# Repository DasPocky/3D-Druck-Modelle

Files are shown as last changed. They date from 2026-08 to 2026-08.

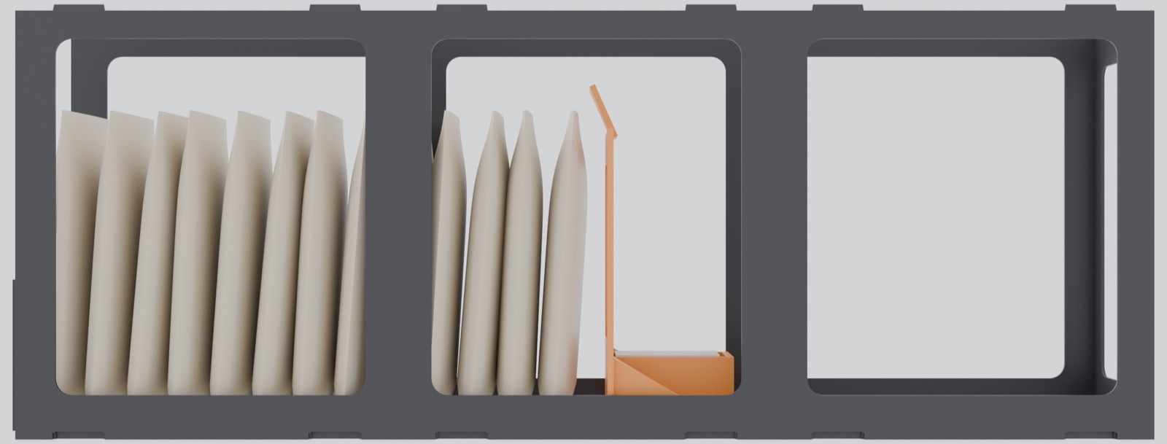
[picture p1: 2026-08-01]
FutterStorage/bilder/web/b_gefuellt.jpg

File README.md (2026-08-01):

# 3D-Druck-Modelle

Meine selbst konstruierten Modelle für den 3D-Druck. Jedes Projekt liegt in
einem eigenen Ordner und ist für sich abgeschlossen — Quelldateien, fertige
STLs, Zeichnungen und Anleitung gehören zusammen.

---

## Projekte

| Projekt | Worum es geht | Druckbett ab |
|---|---|---|
| [FutterStorage](FutterStorage/) | Regalsystem für 85-g-Nassfutterbeutel. Waagerechte Kanäle, eine Konstantkraftfeder schiebt die Beutel nach vorn. 5 × 3 Ebenen = 330 Beutel. | 180 × 180 mm |

---

## Aufbau eines Projekts

Die Ordner folgen überall demselben Schema:

| Ordner | Inhalt |
|---|---|
| `modell/` | Die Quelle — meist OpenSCAD, alle Maße als Variablen |
| `werkzeuge/` | Skripte, die alles Weitere daraus erzeugen |
| `stl/` | Druckfertige Bauteile |
| `zeichnungen/` | Bemaßte SVG-Blätter |
| `bilder/` | Renderings |
| `paket/` | Die fertige Dokumentation zum Weitergeben |

Geändert wird nur in `modell/` und `werkzeuge/`. Alles andere entsteht daraus
neu — die jeweilige Projekt-README sagt, mit welchem Befehl.

Fertige `.zip`-Pakete liegen bewusst nicht im Repo. Sie werden beim Bauen
erzeugt und wären hier nur eine Kopie von allem anderen.

---

## Drucken

Wer nur drucken will, braucht nichts zu installieren: Die STLs liegen fertig
im Repo. Ordner öffnen, `stl/*.stl` herunterladen, in den Slicer ziehen. Die
Projekt-README nennt Material, Schichthöhe und was sonst noch gebraucht wird.

---

## Lizenz

Privates Projekt, keine Garantie auf irgendwas. Nachdrucken und anpassen
ausdrücklich erwünscht.

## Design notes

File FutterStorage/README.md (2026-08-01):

# FutterStorage

Ein gedrucktes Regalsystem für 85-g-Nassfutterbeutel (Purina Gourmet, Felix
und Baugleiches). Waagerechte Kanäle über die volle Schranktiefe, eine
Konstantkraftfeder schiebt die Beutel nach vorne, entnommen wird immer der
vorderste. Die Ebenen stehen direkt aufeinander — kein toter Raum.

Gegriffen wird an der **Oberkante** des Beutels: über ihm bleiben 42 mm
Greifraum, gerade so viel, dass zwei Finger neben die Kante passen. Diese
42 mm bestimmen die Ebenenhöhe von 182,8 mm und damit, dass drei Ebenen
550 mm Fachhöhe brauchen.

**Ausbau:** 5 Spalten × 3 Ebenen = 15 Sorten, 330 Beutel
**Passt in:** 540 × 500 × 550 mm nutzbaren Schrankraum
**Druckbett:** ab 180 × 180 mm (Bambu Lab A1 mini)

---

## Schnellstart

```bash
python3 werkzeuge/stl-bauen.py     # Bauteile erzeugen
python3 werkzeuge/pruefen.py       # prüfen, bevor gedruckt wird
```

Dann `stl/*.stl` in den Slicer. Die vollständige Anleitung liegt in
`paket/index.html` — dort steht auch, was gekauft werden muss.

---

## Aufbau

| Ordner | Inhalt | Herkunft |
|---|---|---|
| `modell/` | Die OpenSCAD-Quelle — alle Maße als Variablen | von Hand |
| `werkzeuge/` | Skripte, die alles Weitere erzeugen | von Hand |
| `stl/` | Druckfertige Bauteile; `segmente/` enthält die 27 Varianten | erzeugt |
| `zeichnungen/` | Sieben bemaßte SVG-Blätter | erzeugt |
| `bilder/` | Renderings in voller Auflösung | erzeugt |
| `paket/` | Die fertige Dokumentation zum Weitergeben | erzeugt |

Geändert wird ausschließlich in `modell/` und `werkzeuge/`. Alles andere
entsteht daraus neu.

### Die Skripte

| Datei | Was sie tut |
|---|---|
| `stl-bauen.py` | Ruft OpenSCAD je Bauteil auf, prüft Stapel und Spalten auf Kollision |
| `pruefen.py` | Wasserdicht, Volumen, Überhänge, Bauraum, Passung — bricht bei Fehlern ab |
| `zeichnungen.py` | Bemaßte SVG-Blätter, prüft sich selbst auf Überdeckungen |
| `rendern.py` | Blender-Szenen mit automatischer Kamerarahmung |
| `schilder.py` | Ein Schild je Futtersorte, als STL und als Bild |
| `symbole-holen.py` | Wandelt die OpenMoji-SVG in OpenSCAD-Polygone |
| `symbole-pruefen.py` | Misst jedes Sortensymbol auf Zentrierung und Größe |
| `webbilder.py` | Verkleinert die Renderings zu JPEG für die Seiten |
| `abgleich.py` | Hält Modell, STL, Zeichnungen und Bilder gegeneinander |
| `seiten.py` | Baut die HTML-Dokumentation und das ZIP |

### Alles neu bauen

```bash
python3 werkzeuge/stl-bauen.py
python3 werkzeuge/pruefen.py
python3 werkzeuge/symbole-pruefen.py
python3 werkzeuge/schilder.py beide
python3 werkzeuge/zeichnungen.py
for s in front mitte end schieber schild kanal explosion gefuellt ebene gesamt \
         entnahme greifraum varianten varianten_spalte; do
    blender -b -P werkzeuge/rendern.py -- $s bilder/b_$s.png
done
python3 werkzeuge/webbilder.py    # verkleinerte JPEG für die Seiten
python3 werkzeuge/seiten.py
python3 werkzeuge/abgleich.py     # prüft alles gegeneinander
```

---

## Anpassen

Alle Maße stehen oben in `modell/katzenfutter-regal.scad`. Die wichtigsten:

| Variable | Standard | Wirkung |
|---|---|---|
| `beutel_breit` | 88 | bestimmt die Spaltenbreite und damit, wie viele Spalten passen |
| `beutel_hoch` | 136 | bestimmt zusammen mit `luft_oben` die Ebenenhöhe |
| `luft_oben` | 42 | Greifraum über dem Beutel — darunter wird die Entnahme zur Fummelei |
| `beutel_dicke` | 19 | bestimmt die Kapazität je Kanal |
| `segment_laenge` | 160 | muss auf das Druckbett passen |
| `passung` | 0,2 | Spiel je Flanke — bei strammem Sitz erhöhen |
| `schild_text` | HUHN | Aufdruck des Schilds |
| `schild_symbol` | huhn | Tiersymbol daneben |

Nach jeder Änderung `stl-bauen.py` und `pruefen.py` laufen lassen. Zeichnungen
und Renderings lesen die Maße selbst aus dem Modell und passen sich an.

---

## Sortensymbole

Die acht Tiersilhouetten stammen aus [OpenMoji](https://openmoji.org)
(CC BY-SA 4.0) und liegen als SVG unter `modell/symbole/`.
`symbole-holen.py` wandelt sie in OpenSCAD-Polygone — OpenSCAD kann kein
SVG lesen. Bei Weitergabe gehört die Namensnennung dazu, Einzelheiten in
[modell/symbole/HERKUNFT.md](modell/symbole/HERKUNFT.md).

---

## Die 27 Segmentvarianten

Ein Segment sitzt an drei Stellen zugleich, und an jedem Rand des Verbunds
fällt weg, was ins Leere greifen würde:

| Achse | Werte | Was sich ändert |
|---|---|---|
| Tiefe | `front` · `mitte` · `end` | Anschlagwand vorne, Rückwand hinten |
| Höhe | `unten` · `mitte` · `oben` | oben ohne Stapelzapfen, unten ohne Taschen |
| Breite | `links` · `mitte` · `rechts` | außen ohne Verbindertasche |

Der Vollausbau braucht 45 Segmente, und jede der 27 Varianten kommt darin
mindestens einmal vor. `stl-bauen.py` gibt die Stückliste am Ende aus.

---

## Wie der Verbund zusammenhält

Zwei Steckverbindungen, beide ohne Zusatzteile und ohne Stützmaterial:

- **Nach oben** laufen die Seitenwände als Zapfen weiter und stecken in Taschen
  im Boden der Ebene darüber.
- **Zur Seite** greift eine Nase am Bodenrand in die Tasche der Nachbarspalte.
  Beide liegen unterhalb des Innenraums und kosten keinen Beutelplatz.

`stl-bauen.py` prüft nach jedem Lauf, dass sich weder gestapelte Ebenen noch
benachbarte Spalten durchdringen.

---

## Was gekauft werden muss

Je Kanal eine **Konstantkraftfeder CF025-0198** (8,8 N, Auszug 557 mm,
Band 12,7 mm) und einen **3-mm-Rundstab aus Edelstahl** als Achse. Sonst
nichts — keine Schrauben, keine Muttern, kein Kleber.

Die Feder wickelt **nicht** direkt auf der Achse: dafür liegt
`stl/trommel.stl` bei, die frei auf ihr läuft. Bezugsquellen, Preise und
die Begründung der Auswahl stehen in [BAUTEILE.md](BAUTEILE.md).

---

## Vor dem Serienstart

`stl/probe.stl` drucken (34 g, gut eine halbe Stunde) und einen echten Beutel
hineinstellen. Passt er mit zwei Millimetern Luft, stimmen alle weiteren Maße.

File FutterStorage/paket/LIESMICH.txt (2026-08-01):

FUTTERSTORAGE
=============

Oeffne index.html im Browser - von dort aus ist alles verlinkt.

  index.html          Uebersicht und Einstieg
  bauanleitung.html   Was gedruckt und gekauft wird, wie es zusammengeht
  technik.html        Wie das Modell entstanden ist, Code und Werkzeuge
  zeichnungen.html    Die fuenf bemassten Blaetter zum Durchblaettern
  galerie.html        Alle zehn Renderings, klickbar in voller Groesse

  stl/                Sieben druckfertige Dateien fuer den Slicer
  zeichnungen/        Sieben bemasste Blaetter (SVG, beliebig skalierbar)
  bilder/             Zehn Renderings in voller Aufloesung (PNG)
  web/                Dieselben Bilder klein - werden von den Seiten geladen
  modell/             Die OpenSCAD-Quelldatei, alle Masse parametrisch

Die Seiten laufen ohne Internet: einfach index.html doppelklicken.
Alle Masse in Millimetern.

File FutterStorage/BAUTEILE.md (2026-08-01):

# Was gekauft werden muss

Alles andere wird gedruckt. Für einen Kanal braucht es genau zwei Zukaufteile:
eine Konstantkraftfeder und einen Rundstab als Achse.

Stand der Recherche: 1. August 2026. Preise und Verfügbarkeit im Shop prüfen.

---

## Wie die Federkraft zustande kommt

Die Feder muss zwei Grenzen einhalten — deshalb steht die Rechnung hier
und nicht nur das Ergebnis.

**Nach unten** begrenzt die Reibung des vollen Stapels:

| | |
|---|---|
| 22 Beutel × 85 g | 1,870 kg = 18,3 N Gewichtskraft |
| Reibbeiwert Folie auf PLA | 0,3 bis 0,4 (am Teil zu messen) |
| **nötige Schubkraft** | **5,5 bis 7,3 N** |

**Nach oben** begrenzt der Beutel selbst. Die volle Federkraft liegt
*immer* auf dem vordersten — egal ob fünf oder fünfundzwanzig dahinter
stehen. Zu viel Kraft drückt ihn flach, er weicht seitlich aus und klemmt:
Im 92-mm-Kanal hat ein 88-mm-Beutel nur 4 mm Spiel. Platzen droht nicht
(8,8 N verteilen sich auf 81 cm² Anlagefläche, das sind rund 1000 Pa —
ein Daumendruck ist hundertmal höher), aber die Verformung reicht zum
Verklemmen. Praktische Obergrenze: **rund 12 N**.

Gewählt ist deshalb eine Feder in der Mitte dieses Fensters.

---

## 1 · Konstantkraftfeder

**Gewählt: CF025-0198** — 8,8 N · Auszug 557 mm · Band 12,7 mm · Rolle Ø 15,5 mm

| Kennwert | Wert | Bedarf |
|---|---|---|
| Zugkraft | 8,8 N | 7,3 N nötig, 12 N Obergrenze |
| Auszug Lmax | 557 mm | 470 mm gebraucht |
| Bandbreite | 12,70 mm | bestimmt Bandnut und Trommel |
| Rolle Ø außen | 15,5 mm | |
| Trommel Ø | 14,5 mm | **wird mitgedruckt**, siehe unten |
| Werkstoff | Federbandstahl 1.4310, rostfrei | |
| Lebensdauer | 4.000 Hübe | |
| Preis | ~16,20 € | Kleinmengen-Listenpreis |

**Bezug:** [sodemann-federn.de](https://www.sodemann-federn.de/produkte/konstantkraftfedern/konstantkraftfedern) ·
alternativ [Febrotec, Halver/NRW](https://www.febrotec.de/de-DE/konstantkraftfedern-rollfedern)
— deutscher Hersteller, Preise auf Anfrage.

### Warum nicht die stärkere Feder?

Die erste Auslegung nahm die CF030-0237 mit 10,5 N — die stärkste, die ins
Raster passte. Das ist die 1,26-fache Reserve über dem Bedarf und bringt
nichts außer mehr Druck auf den vordersten Beutel. Ihr 15-mm-Band verlangte
zudem eine breitere Nut im Boden und eine größere Trommel.

### Andere Feder einsetzen

Passend ist alles, was **8 bis 12 N** liefert und mindestens **480 mm**
auszieht. Im Modell sind dafür vier Zeilen zu ändern:

```openscad
feder_kraft   = 8.8;   // N
feder_band_b  = 12.7;  // Bandbreite
feder_auszug  = 557;   // Lmax
feder_rolle_d = 15.5;  // Rolle außen
```

Bandnut, Federkammer und Trommel rechnen sich daraus.
`pruefen.py` schlägt an, wenn die Feder zu schwach, zu stark oder zu kurz ist.

### Der Preis ist der wunde Punkt — und es gibt eine Alternative

16,20 € je Kanal sind beim Vollausbau **243 €**, und der Listenpreis ist bei
allen Größen etwa gleich: Er ist ein Kleinmengen-Mindestpreis, kein
Materialpreis.

Dieselbe Bauart steckt in **Warenpushern für Ladenregale** — Massenware.
Bei [Sommer International](https://www.sommer-handel.de/einhaengematerialzubehoer):

| Artikel | Preis |
|---|---|
| Warenpusher **inkl. Feder**, ohne Haken und Adapter | **0,60 €** |
| Warenpusher inkl. Feder, Haken 200 mm, Lochwandadapter | 1,69 € |
| Warenpusher inkl. Feder, Haken 300 mm, Lochwandadapter | 1,81 € |
| Warenpusher inkl. Feder, Haken 400 mm, Lochwandadapter | 1,94 € |

Das ist **Faktor 27** gegenüber dem Federspezialisten. Für 15 Kanäle:
9 € statt 243 €.

**Was dafür noch zu klären ist.** Weder Zugkraft noch Auszugslänge stehen
in den Shops; beide gibt es nur auf Anfrage. Aus dem Verwendungszweck
lässt sich abschätzen:

- Der Auszug muss zu den Hakenlängen passen, also mindestens **400 mm**.
  Wir brauchen 470 mm — knapp, aber in der richtigen Größenordnung.
- Die Kraft dürfte bei **2 bis 5 N** liegen (Blisterware auf Lochwandhaken).
  Wir brauchen 7,3 N. Falls sie zu schwach ist: **zwei Federn parallel**,
  ihre Kräfte addieren sich. Dann 18 € statt 9 €.

**Die Gehäusemaße braucht es nicht.** Der Hersteller gibt sie nicht an,
und aus den Produktbildern lassen sie sich nicht ableiten — dieselbe Kante
misst dort je nach Bildzeile 184 bis 268 Pixel, die Perspektive verzerrt zu
stark. Deshalb ist die Aufnahme im Schieber als **Wanne** gebaut, nicht als
Passung: ein Boden mit zwei Seitenwänden und zwei Querschlitzen für
Kabelbinder. Damit hält jedes Gehäuse bis 46 × 30 × 26 mm, ohne dass ein
Maß stimmen muss.

**Was zu prüfen bleibt**, sobald ein Stück da ist:

- **Zugkraft** — Feder senkrecht an einer Küchenwaage ausziehen, angezeigte
  Gramm mal 0,00981 ergibt Newton. **750 g ≈ 7,3 N** ist die Zielmarke.
- **Auszugslänge** — mit dem Zollstock, gebraucht werden 470 mm.

Reicht die Kraft nicht: zwei Gehäuse nebeneinander in dieselbe Wanne,
ihre Kräfte addieren sich.

Das Modell ist auf einen Bereich von 8 bis 12 N ausgelegt und braucht nur
vier geänderte Zahlen — es funktioniert mit jeder Feder, die passt.

## 2 · Achse Ø 3 mm

**Gewählt: Edelstahl-Rundstab V2A, 3 mm × 500 mm — 1,05 €**

[stahl-shop24.de](https://www.stahl-shop24.de/Edelstahl-Rundstab-3mm-500mm) ·
Werkstoff 1.4301, blank gezogen, Toleranz h9.

Ein 500-mm-Stab reicht für fünf Achsen à 90 mm. Ablängen mit Trennscheibe oder
Seitenschneider und Feile.

| Alternative | Werkstoff | Länge | Preis | Anmerkung |
|---|---|---|---|---|
| Silberstahl 1.2210 | geschliffen, poliert | 500 mm | 8,33 € | präziser, achtfacher Preis — nur bei hoher Zyklenzahl sinnvoll |
| Messing-Rundstab | hartgezogen | 1000 mm | 3,80 € | weicher, korrosionsfrei |

### Filament taugt hier nicht

Naheliegend, aber falsch: Standard-Filament ist 1,75 oder 2,85 mm, nicht 3,0.
Ein 2,85er hätte 0,15 mm Spiel in der Bohrung, und PLA kriecht unter der
Dauerlast der Federrolle. Für einen Wegwerf-Prototyp genügt es, für den
Dauerbetrieb nicht.

---

## 3 · Die Trommel wird gedruckt

**Die Feder darf nicht auf der 3-mm-Achse aufwickeln.** Ihr natürlicher
Innendurchmesser liegt bei 11–17 mm; der Hersteller verlangt eine Trommel
10–20 % über diesem Maß. Ein zu enger Wickel erhöht die Biegespannung im Band
und verkürzt die Lebensdauer.

Deshalb liegt `stl/trommel.stl` bei: Ø 14,5 mm Wickelfläche, 14,7 mm breit,
mit Bordscheiben gegen seitliches Ablaufen, Bohrung 3,5 mm — sie läuft frei auf der
Achse. Liegend drucken, dann ist die Bohrung rund und es braucht keine Stützen.

---

## 4 · Regeln für den Umgang mit der Feder

- **Mindestens 1½ Windungen** müssen bei vollem Auszug auf der Trommel bleiben.
- Band **geradlinig** herausführen, keine seitliche Ablenkung — dafür ist die
  Bodennut da.
- Band **niemals knicken, falten oder über scharfe Kanten** laufen lassen. Nicht
  kürzen, bohren oder erwärmen.
- **Die Bandkanten sind scharf.** Bei der Montage Handschuhe und Schutzbrille
  tragen, die Rolle kontrolliert halten — sie wickelt sich beim Loslassen
  schlagartig zurück.

---

## 5 · Kosten

| Position | Menge | Preis |
|---|---|---|
| Konstantkraftfeder CF025-0198 | 1 | ~16,20 € |
| Edelstahl-Rundstab 3 × 500 mm | 1 | 1,05 € |
| **Material je Kanal** | | **~17,25 €** |
| Versand (zwei Shops) | | ~10–14 € |

Der Versand macht fast die Hälfte aus. Für den Vollausbau mit 15 Kanälen
lohnt eine Sammelbestellung; bei Mehrfachabnahme sinkt der Stückpreis der
Federn deutlich.

---

## Quellen

- Sodemann-Federn, Konstantkraftfedern — <https://www.sodemann-federn.de/produkte/konstantkraftfedern/konstantkraftfedern>
- Febrotec GmbH, Rollfedern — <https://www.febrotec.de/de-DE/konstantkraftfedern-rollfedern>
- Lesjöfors, Rollfedern (Sonderfertigung) — <https://www.lesjofors.com/de/produkte/flachfedern/rollfedern/>
- Stahl-Shop24, Edelstahl-Rundstahl — <https://www.stahl-shop24.de/Edelstahl/Edelstahl-rund/>

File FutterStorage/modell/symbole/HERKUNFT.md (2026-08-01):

# Herkunft der Sortensymbole

Die acht Silhouetten stammen aus **OpenMoji** — dem freien Emoji-Satz der
Hochschule für Gestaltung Schwäbisch Gmünd.

- Projekt: <https://openmoji.org>
- Lizenz: **CC BY-SA 4.0** — <https://creativecommons.org/licenses/by-sa/4.0/>

| Datei | Emoji | Unicode |
|---|---|---|
| `huhn.svg` | 🐓 Rooster | U+1F413 |
| `rind.svg` | 🐄 Cow | U+1F404 |
| `fisch.svg` | 🐟 Fish | U+1F41F |
| `kaninchen.svg` | 🐇 Rabbit | U+1F407 |
| `ente.svg` | 🦆 Duck | U+1F986 |
| `truthahn.svg` | 🦃 Turkey | U+1F983 |
| `lamm.svg` | 🐑 Ewe | U+1F411 |
| `wild.svg` | 🦌 Deer | U+1F98C |

Verwendet wird jeweils die `color`-Gruppe, deren Flächen zu einer
geschlossenen Silhouette vereinigt werden — Strichzeichnungen wären als
0,6 mm tiefe Gravur nicht druckbar.

Zwei Abweichungen, beide aus der Sichtprüfung:

- Für **Huhn** wird 🐓 Rooster genommen, nicht 🐔 Chicken. Letzteres zeigt
  ein Küken von vorn; als Silhouette wird daraus eine Knolle, in der kein
  Tier mehr zu erkennen ist.
- Beim **Hirsch** kommt zusätzlich die `line`-Gruppe dazu, verdickt zu
  druckbaren Strichen. Das Geweih steckt dort und nicht in den Farbflächen
  — ohne es ist das Tier von Lamm und Rind nicht zu unterscheiden.

`werkzeuge/symbole-holen.py` wandelt die SVG in OpenSCAD-Polygone und
schreibt `modell/sortensymbole.scad`. Die SVG liegen mit im Repo, damit
der Bau ohne Internetzugang funktioniert und nachvollziehbar bleibt,
welche Fassung verwendet wurde.

**Weitergabe:** CC BY-SA verlangt Namensnennung und dieselbe Lizenz für
Bearbeitungen. Wer das Paket weitergibt, muss diesen Hinweis mitgeben.

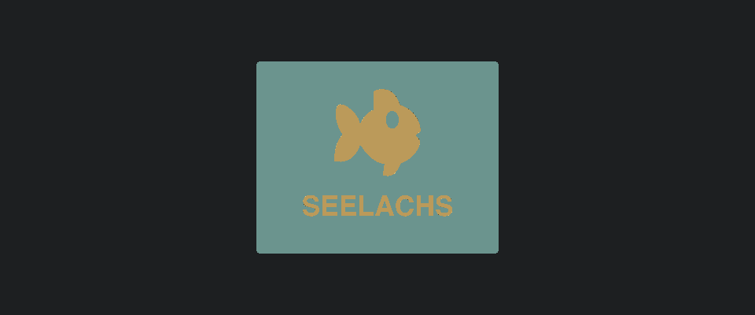
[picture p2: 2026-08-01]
FutterStorage/paket/schilder/12-fisch.png

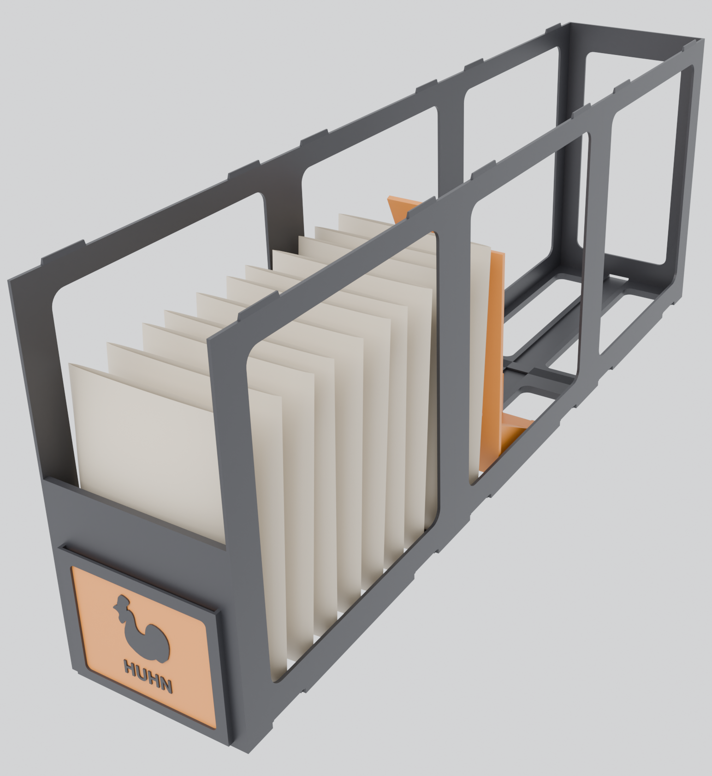
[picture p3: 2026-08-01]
FutterStorage/bilder/b_kanal.png

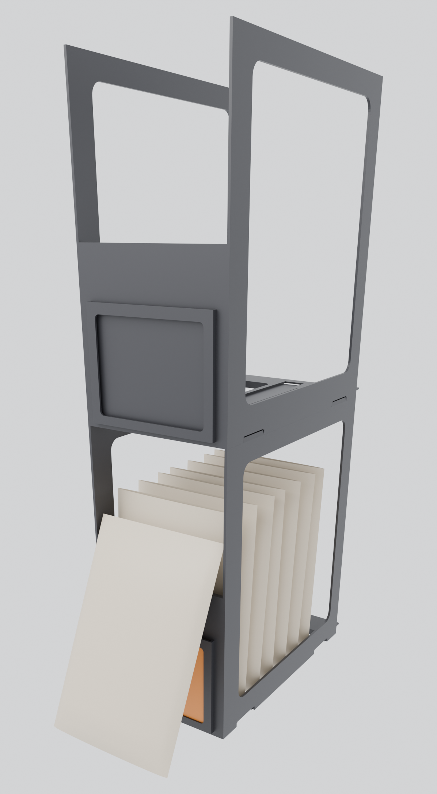
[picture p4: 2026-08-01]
FutterStorage/paket/bilder/10-entnahme.png

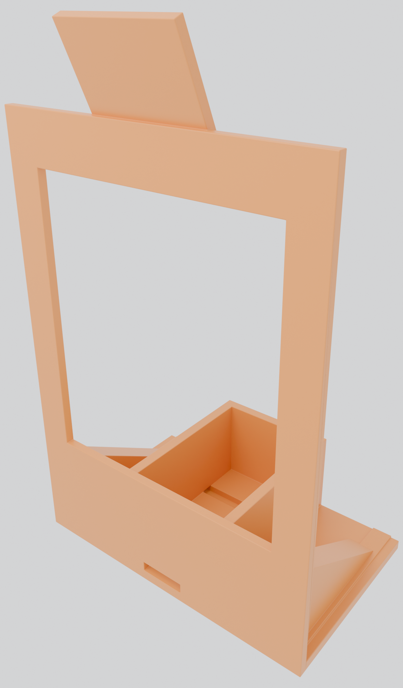
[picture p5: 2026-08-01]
FutterStorage/paket/bilder/04-schieber.png

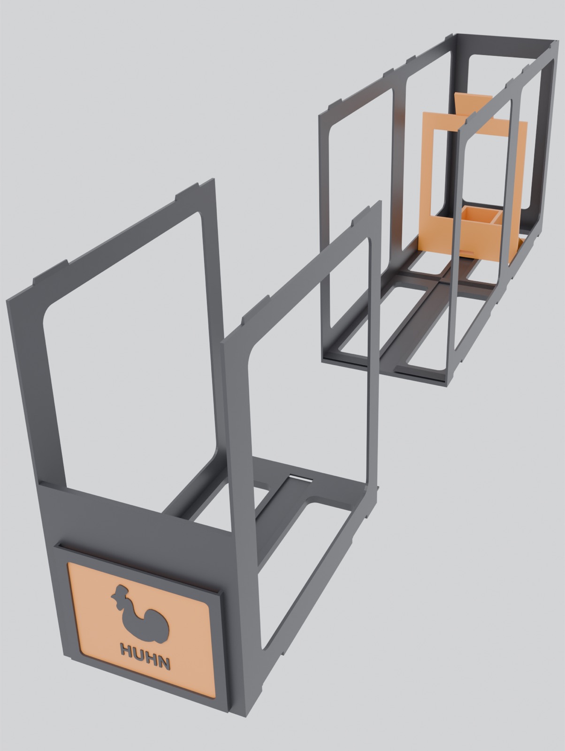
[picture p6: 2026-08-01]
FutterStorage/paket/web/07-explosion.jpg

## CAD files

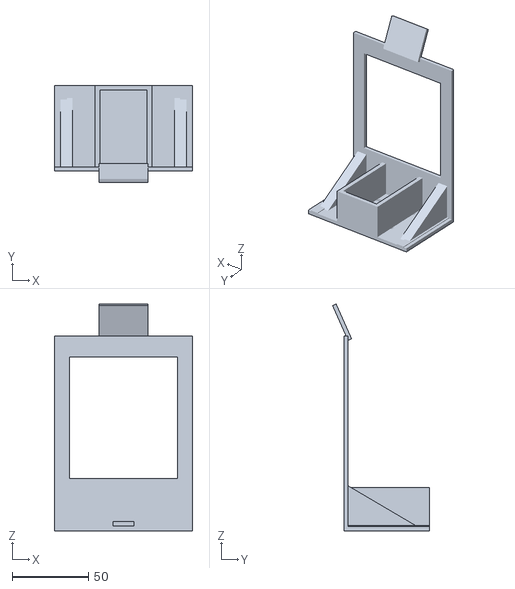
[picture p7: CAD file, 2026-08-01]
FutterStorage/paket/stl/schieber.stl
90.8 x 63.6 x 148.9

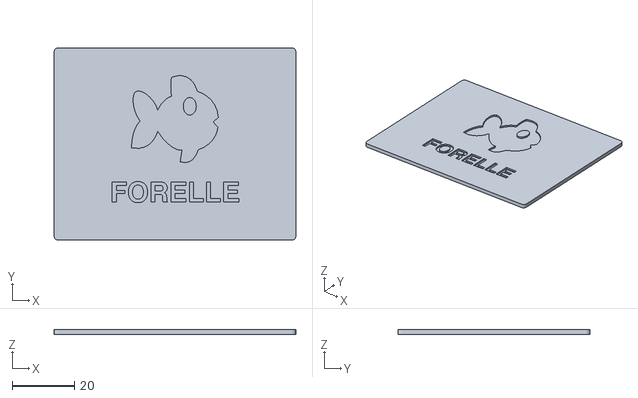
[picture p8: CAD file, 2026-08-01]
FutterStorage/paket/stl/schilder/10-forelle.stl
78.0 x 62.0 x 1.50

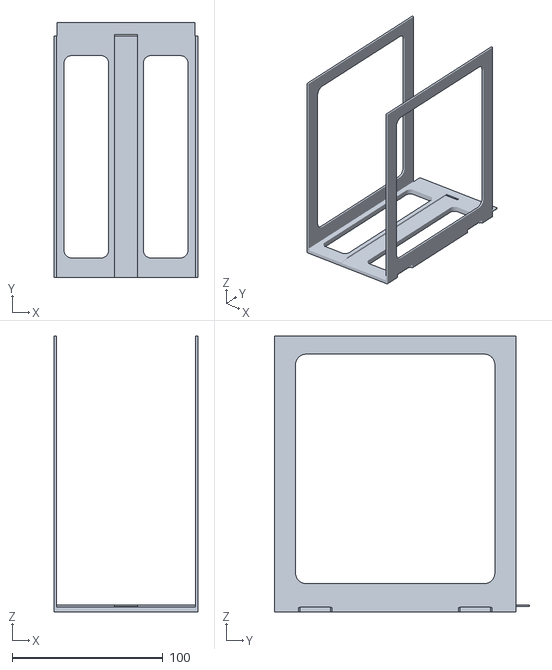
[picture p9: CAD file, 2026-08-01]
FutterStorage/stl/segmente/mitte-oben-links.stl
95.2 x 169.0 x 182.8

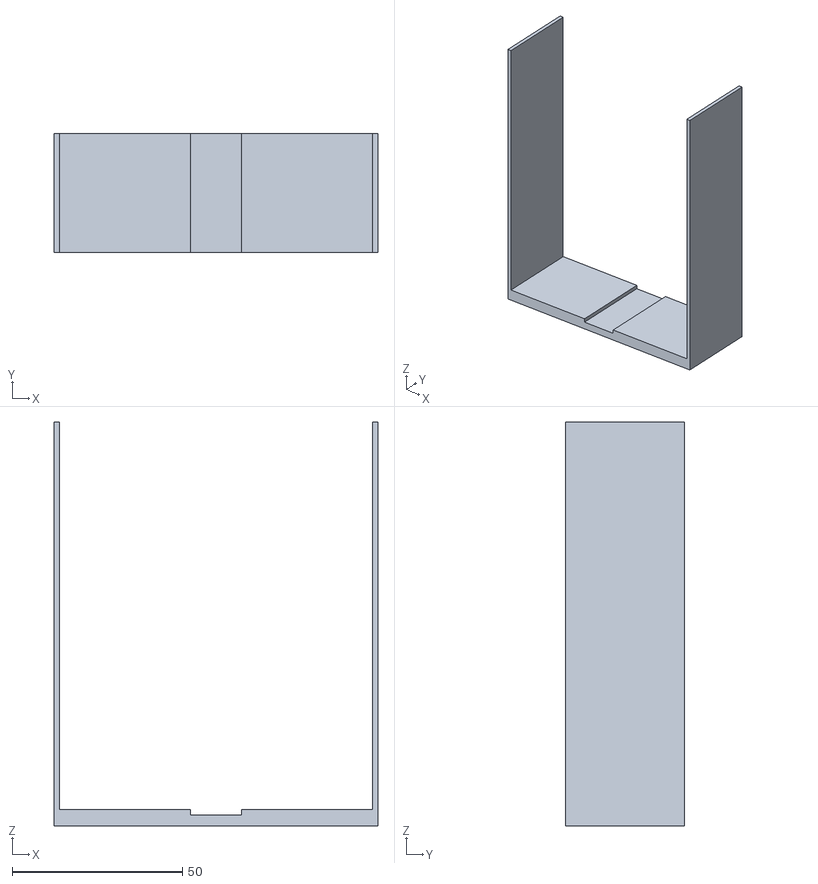
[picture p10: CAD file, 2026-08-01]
FutterStorage/paket/stl/probe.stl
95.2 x 35.0 x 118.8

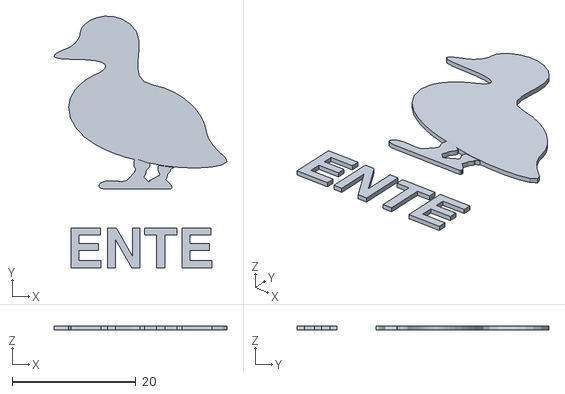
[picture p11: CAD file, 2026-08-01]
FutterStorage/paket/stl/schilder/06-ente-text.stl
28.0 x 40.7 x 0.6

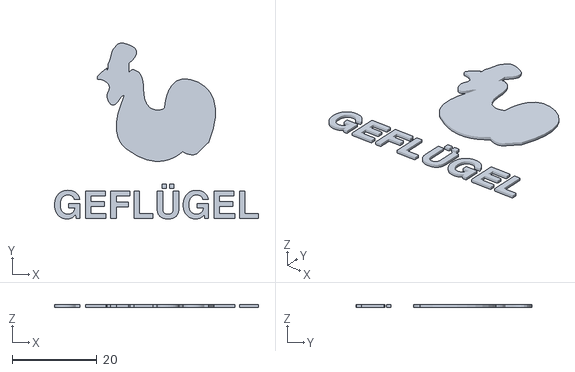
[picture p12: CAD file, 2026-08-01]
FutterStorage/stl/schilder/11-gefluegel-text.stl
48.3 x 41.6 x 0.6

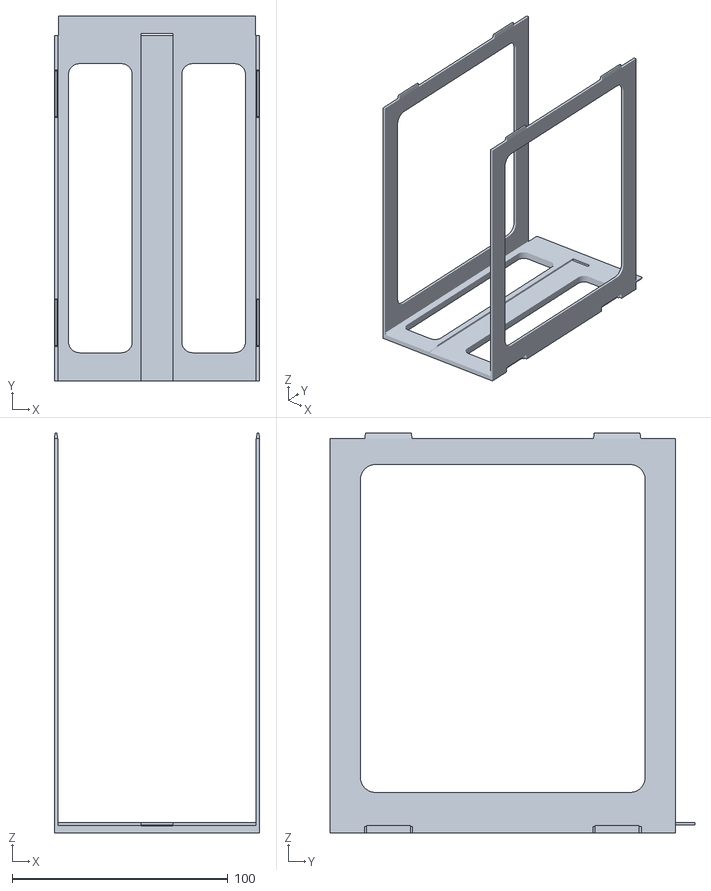
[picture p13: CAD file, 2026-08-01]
FutterStorage/stl/segmente/mitte-mitte-mitte.stl
95.2 x 169.0 x 185.4

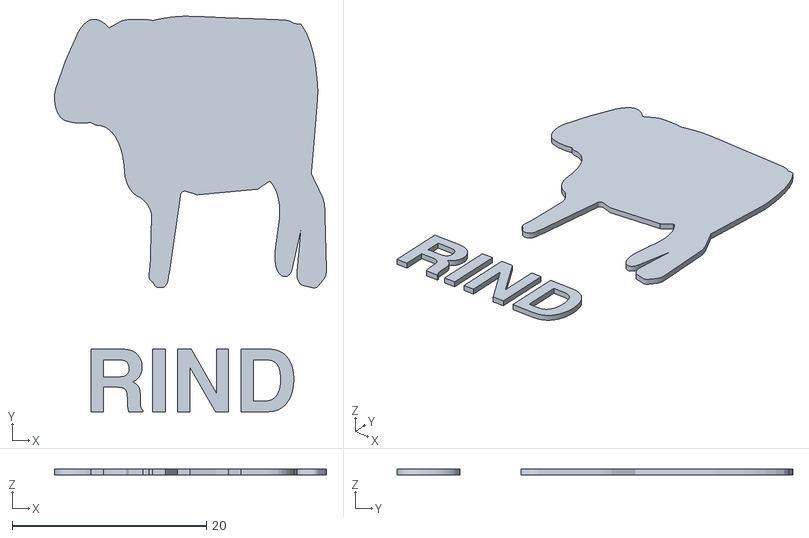
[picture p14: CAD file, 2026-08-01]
FutterStorage/paket/stl/schilder/02-rind-text.stl
28.0 x 40.7 x 0.6

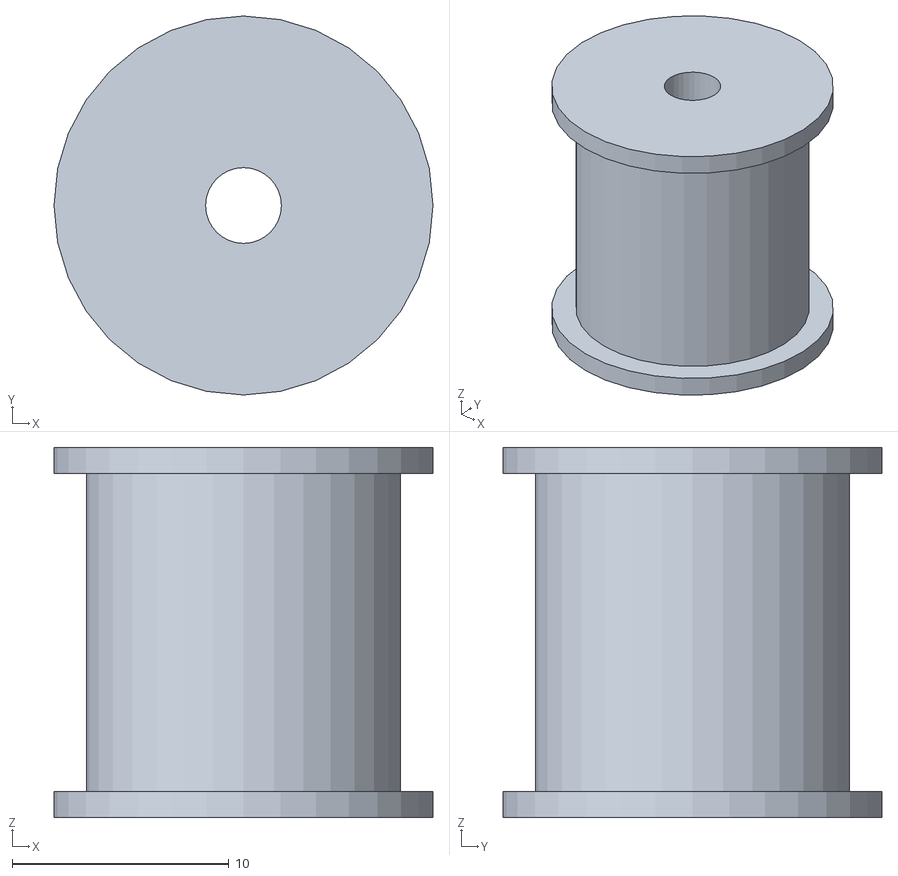
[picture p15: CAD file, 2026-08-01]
FutterStorage/paket/stl/trommel.stl
17.5 x 17.5 x 17.1

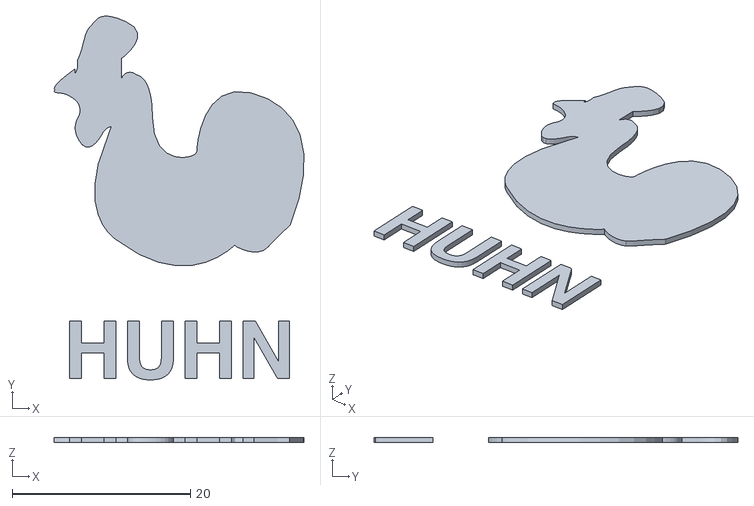
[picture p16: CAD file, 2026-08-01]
FutterStorage/stl/schild-text.stl
28.0 x 40.8 x 0.6

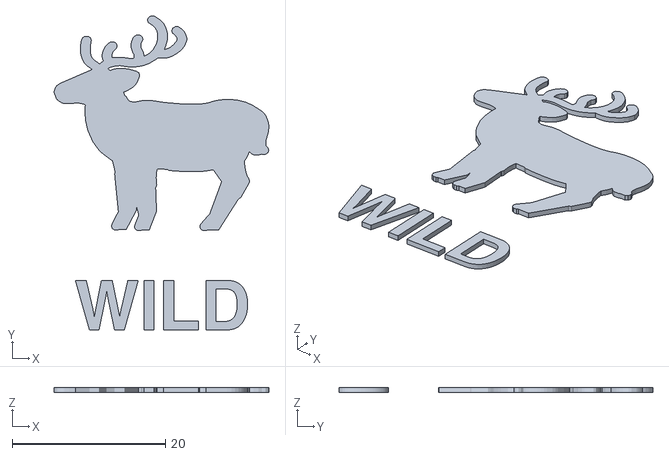
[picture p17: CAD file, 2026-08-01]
FutterStorage/paket/stl/schilder/09-wild-text.stl
28.0 x 41.0 x 0.6

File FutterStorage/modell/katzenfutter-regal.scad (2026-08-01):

// =====================================================================
//  Katzenfutter-Beutel Regalsystem
//
//  Prinzip: waagerechte Kanäle über die volle Schranktiefe. Die Beutel
//  stehen hochkant hintereinander, ein Schieber drückt sie nach vorne.
//
//  Entnommen wird NACH VORNE: der Beutel ragt 44 mm über die Frontwand
//  hinaus. Gefasst wird er an seiner OBERKANTE - dort greifen Daumen und
//  Zeigefinger zu und ziehen ihn nach vorne heraus. Der Platz dafür ist
//  der Greifraum über dem Beutel (luft_oben), nicht die Frontwand: vorne
//  ist der Kanal oberhalb der Wand ohnehin offen.
//
//  Deshalb hat die Frontwand auch keine Griffmulde. Sie säße dort, wo die
//  Hand gar nicht hinfasst, und nähme nur dem Schild Platz weg.
//
//  Die Frontwand ist 92 mm hoch - hoch genug, dass der Schiebedruck den
//  vordersten Beutel nicht darüber hinauskippt (Angriffspunkt bei halber
//  Beutelhöhe, also 68 mm).
//
//  Koordinaten: X = Breite, Y = Tiefe (nach hinten), Z = Höhe.
//               Y = 0 ist vorne, dort wird entnommen.
//  Alle Maße in mm.
// =====================================================================

/* [Was soll gerendert werden] */
// segment = Kanalsegment (Typ über segment_typ), schieber, schild,
// trommel = Wickeltrommel für die Feder, probe = Passprobe,
// layout = Vorschau im Schrank, schnitt = Längsschnitt,
// test = Kollisionsprüfung gestapelter Ebenen (Ergebnis muss leer sein)
TEIL = "segment";  // [segment, schieber, schild, schild_text, verbinder, trommel, probe, layout, schnitt, test]

// Ein Segment sitzt an drei Stellen zugleich - in der Tiefe, in der Höhe
// und in der Breite. Jede Achse hat ihren eigenen Typ, weil an jedem Rand
// des Verbunds etwas weggelassen wird, das im Inneren gebraucht wird.

// Tiefe (Y): front = vorderstes Segment mit Anschlagkante und Schildhalter
//            mitte = beidseitig offenes Zwischenstück, beliebig oft
//            end   = hinterstes Segment mit Rückwand und Bandhaken
segment_typ = "front";  // [front, mitte, end]

// Höhe (Z): oben  = oberste Ebene, ohne Stapelzapfen - sonst stünden
//                   Zapfen frei nach oben ab
//           unten = unterste Ebene, ohne Zapfentaschen im Boden - dort
//                   kommt nichts mehr darunter
//           mitte = beides, Zapfen oben und Taschen unten
ebene_typ = "mitte";  // [unten, mitte, oben]

// Breite (X): links  = linke Randspalte, ohne Verbindertasche nach links
//             rechts = rechte Randspalte, ohne Tasche nach rechts
//             mitte  = beide Taschen, verbindet nach beiden Seiten
spalte_typ = "mitte";  // [links, mitte, rechts]

/* [Beutel-Maße] */
// Gemessen an einem echten 85-g-Beutel, ungequetscht.
// Höhe des aufrecht stehenden Beutels
beutel_hoch = 136;
// Breite des Beutels -> bestimmt die Kanalbreite
beutel_breit = 88;
// Dicke eines Beutels. Sie lassen sich leicht zusammendrücken, im Stapel
// rechnen wir deshalb mit etwas weniger als dem Maximalmaß von 20 mm.
beutel_dicke = 19;
// Luft in der Breite
spiel = 4;
// Luft über dem Beutel. Das ist der Greifraum: Entnommen wird, indem man
// den Beutel an seiner Oberkante fasst und nach vorne herauszieht. Dafür
// müssen zwei Finger neben die Beutelkante passen - unter 40 mm wird das
// zur Fummelei. 42 mm ergibt eine Ebenenhöhe von 182,8 mm; drei Ebenen
// brauchen damit 548,4 mm Fachhöhe.
luft_oben = 42;

/* [Kanal] */
// Länge eines Segments. 160 mm passt auf ein 180er Druckbett.
segment_laenge = 160;
// Wie viele Segmente bilden einen Kanal (nur für Layout und Kapazität)
segment_anzahl = 3;
// Höhe der Frontwand. Muss über dem Angriffspunkt des Schiebedrucks
// liegen (halbe Beutelhöhe = 68 mm), sonst kippt der vorderste Beutel
// darüber hinaus. 92 mm gibt Sicherheit und lässt den Beutel 44 mm
// herausragen. Eine Griffmulde hat die Wand nicht - gegriffen wird oben
// an der Beutelkante, siehe luft_oben.
anschlag_hoehe = 92;

/* [Schrank] */
// Nutzbare Breite: 545 mm abzüglich Scharnier, sicherheitshalber 540
schrank_breite = 540;
schrank_tiefe = 500;
// Fachhöhe von der Standfläche bis zur Unterkante dessen, was darüber kommt.
// Der Regalboden wird dafür höher gesetzt: 550 mm reichen für drei Ebenen
// à 182,8 mm (548,4 mm) und lassen jeder Ebene 42 mm Greifraum über dem
// Beutel. Mit den ursprünglichen 520 mm blieben nur 28 mm - zu wenig, um
// den Beutel oben zu fassen.
schrank_hoehe = 550;
// nur für die layout-Vorschau
spalten = 5;
ebenen = 3;

/* [Wandstärken] */
wand = 1.6;
boden = 2.4;

/* [Material sparen] */
fenster = true;
boden_offen = true;

/* [Konstantkraftfeder] */
// Der Schieber legt bis zu 480 mm zurück. Ein Gummiband kann das nicht:
// es müsste vorne schon gespannt sein und wäre hinten um über 1500 %
// gedehnt. Deshalb eine Konstantkraftfeder - ein aufgerolltes Stahlband,
// das über den ganzen Weg gleich stark zieht. Die Rolle sitzt im Schieber,
// das Bandende hängt vorne im Haken des Frontsegments.
bandnut = true;
// Nut im Boden, in der das Federband läuft
bandnut_breite = 15;   // Band + 2 mm Luft
bandnut_tiefe = 1.6;

// ---------------------------------------------------------------------
//  Federauswahl - die Kraft ergibt sich aus dem Beutelgewicht
// ---------------------------------------------------------------------
// Die Feder schiebt gegen die Reibung des ganzen Stapels. Nach unten ist
// sie also durch den vollen Kanal begrenzt, nach oben durch den Beutel
// selbst: die volle Federkraft liegt IMMER auf dem vordersten, egal wie
// viele dahinterstehen. Zu viel Kraft drückt ihn flach, er weicht seitlich
// aus und klemmt - im 92er Kanal hat ein 88er Beutel nur 4 mm Spiel.
//
//   Gewicht im vollen Kanal   25 × 85 g = 2,125 kg = 20,9 N
//   Reibbeiwert Folie auf PLA 0,3 bis 0,4 (gemessen wird das erst am Teil)
//   -> nötig                  6,3 bis 8,3 N
//   -> Obergrenze             rund 12 N, darüber verformt der Beutel merklich
//
// Gewählt: CF025-0198 mit 8,8 N. Sie deckt den ungünstigen Reibungsfall ab
// und bleibt deutlich unter der Quetschgrenze. Die zuvor eingetragene
// CF030-0237 hatte 10,5 N - unnötig viel, und ihr 15-mm-Band verlangte eine
// breitere Nut und eine größere Trommel.
//
// Andere Feder? Nur diese drei Zeilen ändern, alles Weitere rechnet sich
// daraus. Passend ist, was 8 bis 12 N liefert und mindestens 480 mm auszieht.
feder_kraft   = 8.8;   // N, konstant über den Weg
feder_band_b  = 12.7;  // Bandbreite
feder_auszug  = 557;   // Lmax laut Datenblatt - darüber reißt die Feder
feder_rolle_d = 15.5;  // Außendurchmesser der aufgerollten Feder

feder_achse_d = 3.2;   // Bohrung für die Achse: 3-mm-Rundstab, Spielpassung

// Zwei Wege, dieselbe Feder unterzubringen:
//
//   "pusher" - Fertiges Federgehäuse aus einem Warenpusher für Ladenregale
//              (z. B. Sommer International, Art. 950005801411, 0,60 €).
//              Darin sitzt dieselbe Konstantkraftfeder wie unten, nur als
//              Massenware statt als Industrie-Ersatzteil - Faktor 27 im
//              Preis. Der Schieber bekommt dafür eine Klemmtasche; Trommel
//              und Achse entfallen ganz.
//
//   "rolle"  - Lose Feder auf gedruckter Trommel und 3-mm-Achse. Braucht
//              zwei Teile mehr, dafür sind die Federdaten dokumentiert.
//
// Die Maße des gekauften Gehäuses gibt der Hersteller nicht an, und aus den
// Produktbildern lassen sie sich nicht ableiten - dieselbe Kante misst dort
// je nach Bildzeile 184 bis 268 Pixel, die Perspektive verzerrt zu stark.
//
// Deshalb ist die Aufnahme als WANNE gebaut, nicht als Passung: ein Boden
// mit zwei Seitenwänden und zwei Querschlitzen für Kabelbinder. Damit hält
// jedes Gehäuse in diesem Größenbereich, ohne dass ein Maß stimmen muss.
// Wer die Maße kennt, kann die Wanne enger machen - nötig ist es nicht.
feder_bauart = "pusher";  // [pusher, rolle]

pusher_l = 46;         // Wannenlänge - nimmt Gehäuse bis 46 mm auf
pusher_b = 30;         // Wannenbreite - nimmt Gehäuse bis 30 mm auf
pusher_h = 26;         // Wannentiefe
pusher_spiel = 0.4;    // Luft an den Wänden
binder_b = 4.0;        // Schlitzbreite für den Kabelbinder (3-mm-Binder)
binder_h = 2.2;        // Schlitzhöhe

// Die Feder wickelt NICHT auf der 3-mm-Achse: ihr natürlicher
// Innendurchmesser liegt bei 11-17 mm. Der Hersteller verlangt eine
// Trommel 10-20 % über diesem Maß. Zu klein heißt höhere Biegespannung
// und kürzere Lebensdauer. Die Trommel wird mitgedruckt (TEIL="trommel")
// und läuft frei auf der Achse.
trommel_d = 14.5;      // Wickeldurchmesser, 10-20 % über dem Innen-Ø
trommel_b = 14.7;      // Wickelbreite = Band + 2 mm Luft.
                       // Fester Wert, keine Formel: die Werkzeuge
                       // lesen aus dieser Datei nur Zahlen aus.
trommel_spiel = 0.25;  // Luft auf der Achse, damit sie frei dreht
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

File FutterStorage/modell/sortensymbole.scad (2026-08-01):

// =====================================================================
//  Sortensymbole - ERZEUGT, nicht von Hand aendern
//
//  Quelle:  modell/symbole/*.svg  (OpenMoji, CC BY-SA 4.0)
//  Erzeugt: werkzeuge/symbole-holen.py
//
//  Jede Silhouette ist die vereinigte color-Gruppe der OpenMoji-Datei,
//  auf ein Feld von 20 x 20 um den Nullpunkt gebracht. Dass sie mittig
//  liegt, prueft werkzeuge/symbole-pruefen.py nach.
//
//  Namensnennung gehoert bei Weitergabe dazu - siehe
//  modell/symbole/HERKUNFT.md
// =====================================================================


// huhn - 3 Flaechen, 214 Punkte
module sym_huhn() {
    union() {
        polygon([[4.47,-7.43], [3.87,-7.86], [3.10,-8.28], [2.16,-8.64], [1.05,-8.87], [-0.21,-8.89], [-1.63,-8.65], [-3.19,-8.09], [-4.89,-7.12], [-5.01,-7.06], [-5.30,-6.86], [-5.70,-6.50], [-6.12,-5.97], [-6.48,-5.24], [-6.72,-4.30], [-6.74,-3.12], [-6.48,-1.68], [-6.48,-1.67], [-6.48,-1.66], [-6.47,-1.65], [-6.47,-1.64], [-6.47,-1.63], [-6.46,-1.62], [-6.46,-1.61], [-6.45,-1.60], [-4.71,2.87], [-4.69,2.90], [-4.68,2.93], [-4.68,2.97], [-4.67,3.00], [-4.66,3.03], [-4.66,3.07], [-4.66,3.10], [-4.66,3.14], [-4.66,4.16], [-4.63,4.37], [-4.55,4.55], [-4.42,4.70], [-4.27,4.81], [-4.09,4.87], [-3.90,4.89], [-3.71,4.86], [-3.52,4.77], [-3.52,4.77], [-3.49,4.75], [-3.47,4.74], [-3.44,4.72], [-3.41,4.71], [-3.38,4.70], [-3.35,4.69], [-3.32,4.68], [-3.29,4.67], [-3.16,4.62], [-2.98,4.52], [-2.79,4.35], [-2.60,4.09], [-2.42,3.72], [-2.27,3.21], [-2.16,2.56], [-2.13,1.73], [-1.97,0.51], [-1.57,-0.33], [-1.00,-0.86], [-0.35,-1.12], [0.30,-1.19], [0.87,-1.12], [1.27,-0.97], [1.42,-0.80], [1.44,-0.46], [1.54,0.16], [1.75,0.94], [2.11,1.79], [2.65,2.57], [3.42,3.18], [4.44,3.50], [5.76,3.42], [7.12,2.99], [8.25,2.34], [9.12,1.48], [9.71,0.40], [10.00,-0.90], [9.98,-2.39], [9.62,-4.10], [8.91,-6.00], [8.87,-6.04], [8.73,-6.15], [8.53,-6.31], [8.28,-6.52], [8.00,-6.76], [7.71,-7.02], [7.42,-7.29], [7.15,-7.54], [6.80,-7.79], [6.40,-7.90], [5.98,-7.92], [5.57,-7.86], [5.20,-7.77], [4.90,-7.66], [4.70,-7.58], [4.62,-7.54]]);
        polygon([[-4.66,2.58], [-4.63,2.53], [-4.57,2.39], [-4.51,2.20], [-4.49,1.96], [-4.55,1.70], [-4.73,1.43], [-5.05,1.18], [-5.56,0.98], [-5.65,0.95], [-5.73,0.91], [-5.80,0.87], [-5.87,0.82], [-5.94,0.76], [-6.00,0.70], [-6.05,0.64], [-6.10,0.56], [-6.26,0.33], [-6.45,0.08], [-6.67,-0.15], [-6.92,-0.34], [-7.18,-0.44], [-7.46,-0.43], [-7.75,-0.28], [-8.03,0.05], [-8.17,0.30], [-8.26,0.54], [-8.31,0.76], [-8.32,0.98], [-8.29,1.17], [-8.24,1.35], [-8.17,1.52], [-8.08,1.67], [-8.00,1.82], [-7.95,1.98], [-7.93,2.14], [-7.94,2.31], [-7.98,2.47], [-8.05,2.62], [-8.15,2.76], [-8.27,2.88], [-8.41,2.98], [-8.56,3.08], [-8.73,3.17], [-8.90,3.25], [-9.09,3.32], [-9.29,3.37], [-9.50,3.41], [-9.72,3.42], [-9.93,3.45], [-10.00,3.53], [-9.94,3.66], [-9.77,3.83], [-9.52,4.01], [-9.22,4.21], [-8.89,4.41], [-8.55,4.61], [-8.42,4.69], [-8.32,4.80], [-8.24,4.91], [-8.18,5.05], [-8.14,5.19], [-8.12,5.33], [-8.12,5.49], [-8.14,5.64], [-8.15,5.68], [-8.14,5.71], [-8.13,5.75], [-8.12,5.78], [-8.10,5.82], [-8.08,5.86], [-8.05,5.90], [-8.03,5.95], [-7.89,6.26], [-7.78,6.58], [-7.69,6.88], [-7.61,7.16], [-7.53,7.43], [-7.44,7.67], [-7.33,7.88], [-7.19,8.06], [-6.95,8.30], [-6.74,8.52], [-6.52,8.71], [-6.25,8.83], [-5.92,8.89], [-5.49,8.86], [-4.94,8.73], [-4.23,8.48], [-3.59,8.11], [-3.33,7.69], [-3.34,7.26], [-3.55,6.84], [-3.87,6.46], [-4.21,6.16], [-4.48,5.95], [-4.59,5.88]]);
        polygon([[-8.03,2.88], [-8.19,3.01], [-8.36,3.14], [-8.55,3.26], [-8.75,3.36], [-8.96,3.45], [-9.19,3.52], [-9.43,3.56], [-9.68,3.58], [-9.93,3.62], [-10.00,3.72], [-9.93,3.89], [-9.74,4.10], [-9.46,4.34], [-9.11,4.60], [-8.73,4.86], [-8.35,5.11]]);
    }
}

// rind - 4 Flaechen, 510 Punkte
module sym_rind() {
    union() {
        polygon([[-5.79,5.35], [-5.86,5.39], [-6.29,5.63], [-6.42,5.69], [-6.55,5.74], [-6.69,5.78], [-6.83,5.81], [-6.97,5.82], [-7.12,5.83], [-7.26,5.82], [-7.40,5.80], [-7.40,5.80], [-7.54,5.75], [-7.68,5.69], [-7.81,5.62], [-7.94,5.54], [-8.06,5.45], [-8.17,5.35], [-8.28,5.24], [-8.37,5.12], [-8.50,4.94], [-8.64,4.76], [-8.78,4.58], [-8.90,4.41], [-9.01,4.26], [-9.10,4.14], [-9.16,4.06], [-9.19,4.03], [-9.21,3.99], [-9.26,3.90], [-9.34,3.77], [-9.44,3.60], [-9.54,3.42], [-9.65,3.23], [-9.76,3.04], [-9.87,2.86], [-9.91,2.78], [-9.95,2.68], [-9.98,2.59], [-9.99,2.49], [-10.00,2.39], [-10.00,2.29], [-9.98,2.19], [-9.96,2.09], [-9.96,2.09], [-9.91,1.96], [-9.85,1.84], [-9.77,1.73], [-9.67,1.63], [-9.57,1.54], [-9.45,1.47], [-9.32,1.42], [-9.19,1.38], [-8.94,1.34], [-8.66,1.30], [-8.36,1.28], [-8.03,1.27], [-7.68,1.27], [-7.31,1.31], [-6.93,1.37], [-6.54,1.46], [-6.48,1.48], [-6.42,1.48], [-6.36,1.48], [-6.30,1.48], [-6.24,1.46], [-6.18,1.44], [-6.13,1.41], [-6.08,1.38], [-5.92,1.24], [-5.74,1.07], [-5.54,0.86], [-5.35,0.62], [-5.16,0.36], [-5.01,0.06], [-4.88,-0.27], [-4.81,-0.61], [-4.79,-0.70], [-4.75,-0.78], [-4.70,-0.85], [-4.64,-0.91], [-4.57,-0.96], [-4.49,-1.00], [-4.41,-1.02], [-4.32,-1.03], [-4.09,-1.04], [-3.84,-1.08], [-3.60,-1.14], [-3.36,-1.25], [-3.16,-1.40], [-2.99,-1.61], [-2.88,-1.89], [-2.84,-2.23], [-2.84,-2.30], [-2.85,-2.46], [-2.86,-2.69], [-2.87,-2.97], [-2.89,-3.28], [-2.90,-3.61], [-2.92,-3.94], [-2.93,-4.25], [-2.94,-4.41], [-2.94,-4.58], [-2.93,-4.74], [-2.92,-4.90], [-2.90,-5.06], [-2.88,-5.23], [-2.86,-5.39], [-2.82,-5.55], [-2.82,-5.55], [-2.80,-5.63], [-2.76,-5.71], [-2.71,-5.78], [-2.65,-5.83], [-2.58,-5.88], [-2.50,-5.92], [-2.42,-5.94], [-2.33,-5.95], [-2.12,-5.95], [-2.03,-5.94], [-1.95,-5.92], [-1.87,-5.88], [-1.80,-5.83], [-1.74,-5.78], [-1.69,-5.71], [-1.65,-5.63], [-1.63,-5.54], [-0.90,-2.11], [-0.87,-2.02], [-0.83,-1.93], [-0.76,-1.86], [-0.69,-1.80], [-0.61,-1.75], [-0.51,-1.72], [-0.42,-1.71], [-0.31,-1.72], [0.43,-1.86], [0.44,-1.86], [0.46,-1.87], [0.48,-1.87], [0.49,-1.87], [0.51,-1.87], [0.52,-1.87], [0.54,-1.87], [0.55,-1.87], [4.87,-1.63], [4.89,-1.63], [4.92,-1.63], [4.94,-1.63], [4.96,-1.62], [4.98,-1.62], [5.00,-1.61], [5.02,-1.60], [5.04,-1.59], [5.78,-1.29], [8.64,-1.29], [8.60,-1.24], [8.57,-1.19], [8.54,-1.14], [8.52,-1.09], [8.51,-1.03], [8.50,-0.98], [8.50,-0.92], [8.51,-0.86], [8.99,2.23], [9.00,2.25], [9.00,2.27], [9.00,2.28], [9.00,2.30], [9.00,2.32], [9.00,2.34], [9.00,2.35], [9.00,2.37], [8.98,2.51], [8.95,2.70], [8.91,2.94], [8.86,3.23], [8.81,3.53], [8.74,3.86], [8.67,4.19], [8.58,4.52], [8.48,4.79], [8.34,5.03], [8.17,5.25], [7.96,5.43], [7.73,5.58], [7.48,5.70], [7.21,5.77], [6.92,5.80], [6.20,5.82], [5.36,5.84], [4.44,5.86], [3.48,5.88], [2.53,5.90], [1.61,5.93], [0.77,5.95], [0.05,5.96], [-0.21,5.97], [-0.48,5.97], [-0.74,5.96], [-1.00,5.95], [-1.26,5.94], [-1.53,5.92], [-1.79,5.89], [-2.05,5.87], [-3.43,5.70], [-3.60,5.68], [-3.77,5.66], [-3.94,5.64], [-4.11,5.61], [-4.28,5.58], [-4.45,5.55], [-4.61,5.52], [-4.78,5.48], [-6.15,5.19]]);
        polygon([[-4.08,5.83], [-4.27,5.83], [-4.45,5.83], [-4.62,5.82], [-4.78,5.80], [-4.93,5.78], [-5.08,5.75], [-5.23,5.71], [-5.37,5.66], [-6.12,5.41], [-6.21,5.37], [-6.43,5.28], [-6.74,5.11], [-7.10,4.86], [-7.46,4.52], [-7.77,4.10], [-7.99,3.58], [-8.08,2.95], [-8.02,2.36], [-7.88,1.91], [-7.68,1.60], [-7.44,1.39], [-7.21,1.26], [-7.00,1.20], [-6.86,1.18], [-6.80,1.18], [-6.80,1.18], [-6.51,1.15], [-6.24,1.09], [-5.98,0.98], [-5.73,0.84], [-5.52,0.67], [-5.33,0.46], [-5.17,0.22], [-5.04,-0.04], [-5.01,-0.13], [-4.98,-0.22], [-4.95,-0.32], [-4.93,-0.42], [-4.90,-0.52], [-4.88,-0.62], [-4.87,-0.72], [-4.86,-0.83], [-4.81,-1.08], [-4.71,-1.30], [-4.59,-1.48], [-4.44,-1.63], [-4.28,-1.75], [-4.11,-1.85], [-3.94,-1.92], [-3.78,-1.97], [-3.68,-2.00], [-3.58,-2.04], [-3.48,-2.09], [-3.39,-2.14], [-3.30,-2.20], [-3.22,-2.26], [-3.14,-2.33], [-3.06,-2.41], [-3.06,-2.41], [-3.01,-2.47], [-2.96,-2.54], [-2.92,-2.61], [-2.88,-2.69], [-2.86,-2.77], [-2.84,-2.85], [-2.83,-2.94], [-2.83,-3.02], [-2.87,-3.89], [-2.88,-4.08], [-2.89,-4.27], [-2.91,-4.46], [-2.93,-4.64], [-2.96,-4.83], [-2.98,-5.02], [-3.02,-5.20], [-3.05,-5.39], [-3.05,-5.39], [-3.05,-5.43], [-3.05,-5.46], [-3.05,-5.50], [-3.03,-5.53], [-3.01,-5.57], [-2.99,-5.60], [-2.96,-5.62], [-2.93,-5.64], [-2.93,-5.64], [-2.83,-5.69], [-2.72,-5.73], [-2.62,-5.76], [-2.50,-5.77], [-2.39,-5.78], [-2.28,-5.78], [-2.17,-5.76], [-2.06,-5.74], [-2.06,-5.74], [-1.96,-5.70], [-1.87,-5.66], [-1.79,-5.60], [-1.71,-5.53], [-1.65,-5.45], [-1.59,-5.37], [-1.55,-5.27], [-1.52,-5.17], [-0.64,-1.52], [-0.62,-1.33], [-0.58,-0.97], [-0.55,-0.60], [-0.54,-0.23], [-0.53,0.13], [-0.55,0.50], [-0.57,0.87], [-0.61,1.23], [-0.66,1.60], [-0.69,1.85], [-0.73,2.10], [-0.77,2.33], [-0.80,2.55], [-0.83,2.73], [-0.85,2.89], [-0.87,3.00], [-0.88,3.07], [-0.88,3.12], [-0.90,3.21], [-0.91,3.33], [-0.94,3.47], [-0.96,3.64], [-0.99,3.82], [-1.02,4.01], [-1.06,4.22], [-1.17,4.59], [-1.34,4.92], [-1.57,5.19], [-1.84,5.41], [-2.16,5.58], [-2.51,5.71], [-2.88,5.79], [-3.28,5.83], [-4.08,5.83]]);
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

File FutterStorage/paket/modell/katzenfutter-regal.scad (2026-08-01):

// =====================================================================
//  Katzenfutter-Beutel Regalsystem
//
//  Prinzip: waagerechte Kanäle über die volle Schranktiefe. Die Beutel
//  stehen hochkant hintereinander, ein Schieber drückt sie nach vorne.
//
//  Entnommen wird NACH VORNE: der Beutel ragt 44 mm über die Frontwand
//  hinaus. Gefasst wird er an seiner OBERKANTE - dort greifen Daumen und
//  Zeigefinger zu und ziehen ihn nach vorne heraus. Der Platz dafür ist
//  der Greifraum über dem Beutel (luft_oben), nicht die Frontwand: vorne
//  ist der Kanal oberhalb der Wand ohnehin offen.
//
//  Deshalb hat die Frontwand auch keine Griffmulde. Sie säße dort, wo die
//  Hand gar nicht hinfasst, und nähme nur dem Schild Platz weg.
//
//  Die Frontwand ist 92 mm hoch - hoch genug, dass der Schiebedruck den
//  vordersten Beutel nicht darüber hinauskippt (Angriffspunkt bei halber
//  Beutelhöhe, also 68 mm).
//
//  Koordinaten: X = Breite, Y = Tiefe (nach hinten), Z = Höhe.
//               Y = 0 ist vorne, dort wird entnommen.
//  Alle Maße in mm.
// =====================================================================

/* [Was soll gerendert werden] */
// segment = Kanalsegment (Typ über segment_typ), schieber, schild,
// trommel = Wickeltrommel für die Feder, probe = Passprobe,
// layout = Vorschau im Schrank, schnitt = Längsschnitt,
// test = Kollisionsprüfung gestapelter Ebenen (Ergebnis muss leer sein)
TEIL = "segment";  // [segment, schieber, schild, schild_text, verbinder, trommel, probe, layout, schnitt, test]

// Ein Segment sitzt an drei Stellen zugleich - in der Tiefe, in der Höhe
// und in der Breite. Jede Achse hat ihren eigenen Typ, weil an jedem Rand
// des Verbunds etwas weggelassen wird, das im Inneren gebraucht wird.

// Tiefe (Y): front = vorderstes Segment mit Anschlagkante und Schildhalter
//            mitte = beidseitig offenes Zwischenstück, beliebig oft
//            end   = hinterstes Segment mit Rückwand und Bandhaken
segment_typ = "front";  // [front, mitte, end]

// Höhe (Z): oben  = oberste Ebene, ohne Stapelzapfen - sonst stünden
//                   Zapfen frei nach oben ab
//           unten = unterste Ebene, ohne Zapfentaschen im Boden - dort
//                   kommt nichts mehr darunter
//           mitte = beides, Zapfen oben und Taschen unten
ebene_typ = "mitte";  // [unten, mitte, oben]

// Breite (X): links  = linke Randspalte, ohne Verbindertasche nach links
//             rechts = rechte Randspalte, ohne Tasche nach rechts
//             mitte  = beide Taschen, verbindet nach beiden Seiten
spalte_typ = "mitte";  // [links, mitte, rechts]

/* [Beutel-Maße] */
// Gemessen an einem echten 85-g-Beutel, ungequetscht.
// Höhe des aufrecht stehenden Beutels
beutel_hoch = 136;
// Breite des Beutels -> bestimmt die Kanalbreite
beutel_breit = 88;
// Dicke eines Beutels. Sie lassen sich leicht zusammendrücken, im Stapel
// rechnen wir deshalb mit etwas weniger als dem Maximalmaß von 20 mm.
beutel_dicke = 19;
// Luft in der Breite
spiel = 4;
// Luft über dem Beutel. Das ist der Greifraum: Entnommen wird, indem man
// den Beutel an seiner Oberkante fasst und nach vorne herauszieht. Dafür
// müssen zwei Finger neben die Beutelkante passen - unter 40 mm wird das
// zur Fummelei. 42 mm ergibt eine Ebenenhöhe von 182,8 mm; drei Ebenen
// brauchen damit 548,4 mm Fachhöhe.
luft_oben = 42;

/* [Kanal] */
// Länge eines Segments. 160 mm passt auf ein 180er Druckbett.
segment_laenge = 160;
// Wie viele Segmente bilden einen Kanal (nur für Layout und Kapazität)
segment_anzahl = 3;
// Höhe der Frontwand. Muss über dem Angriffspunkt des Schiebedrucks
// liegen (halbe Beutelhöhe = 68 mm), sonst kippt der vorderste Beutel
// darüber hinaus. 92 mm gibt Sicherheit und lässt den Beutel 44 mm
// herausragen. Eine Griffmulde hat die Wand nicht - gegriffen wird oben
// an der Beutelkante, siehe luft_oben.
anschlag_hoehe = 92;

/* [Schrank] */
// Nutzbare Breite: 545 mm abzüglich Scharnier, sicherheitshalber 540
schrank_breite = 540;
schrank_tiefe = 500;
// Fachhöhe von der Standfläche bis zur Unterkante dessen, was darüber kommt.
// Der Regalboden wird dafür höher gesetzt: 550 mm reichen für drei Ebenen
// à 182,8 mm (548,4 mm) und lassen jeder Ebene 42 mm Greifraum über dem
// Beutel. Mit den ursprünglichen 520 mm blieben nur 28 mm - zu wenig, um
// den Beutel oben zu fassen.
schrank_hoehe = 550;
// nur für die layout-Vorschau
spalten = 5;
ebenen = 3;

/* [Wandstärken] */
wand = 1.6;
boden = 2.4;

/* [Material sparen] */
fenster = true;
boden_offen = true;

/* [Konstantkraftfeder] */
// Der Schieber legt bis zu 480 mm zurück. Ein Gummiband kann das nicht:
// es müsste vorne schon gespannt sein und wäre hinten um über 1500 %
// gedehnt. Deshalb eine Konstantkraftfeder - ein aufgerolltes Stahlband,
// das über den ganzen Weg gleich stark zieht. Die Rolle sitzt im Schieber,
// das Bandende hängt vorne im Haken des Frontsegments.
bandnut = true;
// Nut im Boden, in der das Federband läuft
bandnut_breite = 15;   // Band + 2 mm Luft
bandnut_tiefe = 1.6;
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

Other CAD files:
FutterStorage/stl/schilder/05-truthahn.stl
FutterStorage/stl/segmente/mitte-unten-links.stl
FutterStorage/paket/stl/schild.stl
FutterStorage/stl/schild.stl
FutterStorage/paket/stl/schilder/01-huhn.stl
FutterStorage/paket/stl/schilder/02-rind.stl
FutterStorage/paket/stl/schilder/03-lachs-text.stl
FutterStorage/paket/stl/schilder/03-lachs.stl
FutterStorage/paket/stl/schilder/04-kaninchen-text.stl
FutterStorage/paket/stl/schilder/04-kaninchen.stl
FutterStorage/paket/stl/schilder/05-truthahn-text.stl
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

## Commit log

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2026-08-01 Modell: Greifraum über dem Beutel auf 42 mm
    Entnommen wird, indem man den Beutel an der Oberkante fasst. Dafür
    lagen bisher nur 28 mm zwischen Beutelkante und der Ebene darüber -
    zu wenig für zwei Finger. Mit 42 mm wächst die Ebenenhöhe auf
    182,8 mm; drei Ebenen brauchen 548,4 mm statt 506,4 mm Fachhöhe.
    Der Regalboden wird dafür höher gesetzt.
    [katzenfutter-regal.scad]
2026-08-01 Modell: Griffmulde entfällt, Entnahme richtig beschrieben
    Die Mulde saß in der Frontwand auf halber Höhe - dort, wo beim
    Herausziehen gar keine Hand hinfasst. Gegriffen wird an der OBERKANTE
    des Beutels; der Kanal ist oberhalb der Anschlagwand ohnehin offen.
    Die Mulde nahm damit nur dem Schild Platz weg.
    Der Kopfkommentar behauptete außerdem das Gegenteil des Richtigen
    ("brauchen die Ebenen keinen Greifraum") und nannte Maße, die nicht
    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
    [katzenfutter-regal.scad]
2026-08-01 Modell: Federmaße auf CF030-0237, Wickeltrommel ergänzt
    Die Bauteilrecherche zeigt: Band mit 16 mm bei 8-12 N gibt es nicht ab
    Lager - die Kraft wächst mit Bandbreite mal Banddicke im Quadrat, bei
    15,87 mm Band liegt die Standardfeder schon bei 14,7 N. Gewählt ist
    die CF030-0237 mit 10,5 N, 610 mm Auszug und 15,0 mm Band.
    Wichtiger noch: die Feder wickelte im Modell direkt auf der 3-mm-Achse.
    Das geht nicht - ihr natürlicher Innendurchmesser liegt bei 11-17 mm,
    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
    [katzenfutter-regal.scad]
2026-08-01 Modell: Schieber ragte 4 mm über die eigene Kante hinaus
    rotate([0,-90,0]) legt die Extrusionsrichtung nach -X: jede
    Versteifungsrippe wächst von ihrem Startpunkt aus nach LINKS. Die
    linke Rippe stand deshalb bei xp=4 von 4 bis -4 und machte den
    Schieber 94,8 mm breit - bei 92 mm Kanalbreite hätte er nie
    hineingepasst. Mit xp=12 liegen beide Rippen im Bauteil, der Schieber
    ist 90,8 mm breit und hat 1,2 mm Luft.
    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
    [katzenfutter-regal.scad]
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2026-08-01 Modell: Segmentvarianten nach Ebene und Spalte
    Ein Segment sitzt an drei Stellen zugleich, deshalb jetzt drei Achsen:
    segment_typ front | mitte | end Tiefe (gab es schon)
    ebene_typ unten | mitte | oben Höhe (neu)
    spalte_typ links | mitte | rechts Breite (neu)
    An jedem Rand des Verbunds fällt weg, was ins Leere greifen würde:
    oben keine Stapelzapfen (sie stünden frei ab - genau der Punkt, der
    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
    [katzenfutter-regal.scad]
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2026-08-01 Modell: Sortensymbole neu gezeichnet, Schildsatz repariert
    Die acht Tiere sind neu aufgebaut und liegen jetzt in einer eigenen
    Datei. Drei Fehler waren zu beheben:
    MITTIG. Keines der Symbole war um (0,0) zentriert. resize() im Schild
    skaliert nur, es verschiebt nicht - deshalb saßen alle Tiere rechts
    der Mitte. Jedes Symbol ist jetzt nachweislich zentriert; gemessen wird
    das von werkzeuge/symbole-pruefen.py, das dafür TEIL="symbol" nutzt.
    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
    [katzenfutter-regal.scad, sortensymbole.scad]
2026-08-01 rendern.py: Beutel sichtbar machen, Szenen zur Entnahme
    Auf keinem Bild war zu erkennen, was Beutel ist und wo die Luft darüber
    bleibt - es sah aus, als füllte der Beutel die ganze Kanalhöhe. Drei
    Gründe, alle behoben:
    FARBE. Die Folie war fast so grau wie das PLA. Jetzt ein helles
    Folienbeige, das sich klar vom dunklen Bauteil abhebt.
    OBERKANTE. Die Dickenkurve lief nach oben auf 0,032 zusammen, der Beutel
    endete spitz wie ein Zacken. Mit 0,16 Restdicke bleibt die Siegelnaht als
    Kante stehen - man sieht, wo der Beutel aufhört.
    BILDER. Zwei neue Szenen: "entnahme" zeigt den vordersten Beutel an der
    Oberkante gefasst, mit zwei maßstäblichen Fingern (17,5 mm), die neben
    die Kante gre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
2026-08-01 Druckfertige Bauteile: 27 Segmentvarianten, Trommel, Schieber
    Neu erzeugt aus dem geänderten Modell. Die Segmente liegen jetzt unter
    segmente/ als volle Matrix; die früheren oben/-Varianten entfallen.
    pruefen.py misst die Trommel jetzt entlang der richtigen Achse: sie wird
    liegend gedruckt, damit die Bohrung rund wird, also liegt ihre Breite in
    Z. Gemessen wurde vorher X - das ist der Bordscheiben-Durchmesser, und
    die Prüfung meldete deshalb einen Fehler, den es nicht gab.
    [end-mitte-links.stl, end-mitte-mitte.stl, end-mitte-rechts.stl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]
2026-08-01 Sortenschilder neu: Symbole zentriert, GEFLÜGEL mit Umlaut
    Alle zwölf Schilder aus dem überarbeiteten Modell. Der Aufdruck trägt
    jetzt echte Umlaute - dadurch ist GEFLÜGEL ein Zeichen kürzer als vorher
    und KANINCHEN mit 83,3 mm der breiteste Name, nach dem sich die
    Schriftgröße aller Schilder richtet.
    Das Kaninchen musste ein zweites Mal überarbeitet werden: Die Ohren
    saßen zu tief und zu breit am Kopf und verschmolzen mit ihm zu einem
    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
    [01-huhn-text.stl, 01-huhn.stl, 02-rind-text.stl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]
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2026-08-01 zeichnungen.py: Trommel aufgenommen, Maße aus dem Modell
    Blatt 3 zeigte den Schieber mit einer Federkammer von 17,6 mm - die
    Legende sagte das noch, während die Zeichnung daneben schon 20,6 mm
    bemaßte. Beide Zahlen standen als Text im Skript. Jetzt kommen sie aus
    dem Modell und können nicht mehr auseinanderlaufen.
    Neu ist die Trommel als eigene Ansicht mit Wickeldurchmesser,
    Bordscheiben und Gesamtbreite. Sie steht in der rechten Spalte, wo
    vorher ungenutzte Fläche war.
    Die Achse ist kein Filament mehr: 2,85 mm hätten 0,15 mm Spiel in der
    3-mm-Bohrung, und PLA kriecht unter der Dauerlast der Feder. Das steht
    so auch in BAUTEILE.md.
    Blatt 4 rechnete mit "434" für drei Ebenen - das w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
2026-08-01 Werkzeug webbilder.py, seiten.py auf den neuen Stand
    Die verkleinerten JPEG unter bilder/web/ entstanden bisher von Hand.
    Beim Nachbauen fehlte der Schritt, und nach einer Modelländerung zeigten
    die Seiten wochenalte Bilder, während die PNG daneben schon neu waren.
    webbilder.py schließt die Lücke mit sips, ohne Fremdbibliothek: 12 Bilder,
    1,5 MB statt 30,2 MB.
    seiten.py trug noch die alte Erklärung: "Du greifst ihn dort und durch
    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
    [01-huhn-text.stl, 01-huhn.stl, 02-rind-text.stl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]
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2026-08-01 Renderings, Zeichnungen und Doku zeigen die Segmentvarianten
    Die 27 Varianten gab es zwar als STL, aber nirgends zu sehen: kein Bild,
    keine Zeichnung, kein Wort in der Doku. Ergänzt sind deshalb
    - zwei Renderings: die drei Ebenenlagen und die drei Spaltenlagen
    nebeneinander, dazu ein eigener Galerieblock,
    - eine Variantenmatrix auf Blatt 6 der Zeichnungen, die benennt, was an
    welchem Rand entfällt und wie die Dateien heißen,
    - der Abschnitt in der Bauanleitung mit Bild.
    Dazu das korrigierte Entnahmebild: der herausgezogene Beutel stand
    senkrecht bei y = 3 und damit mitten in der Frontwand - das war der
    sichtbare Durchdringungsfehler. Jetzt kippt er über die Wandkante nach
    vorn, der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
    [01-huhn-text.stl, 01-huhn.stl, 02-rind-text.stl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]
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
